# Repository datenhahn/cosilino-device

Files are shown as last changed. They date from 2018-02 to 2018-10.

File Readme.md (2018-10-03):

# Cosilino - Remote control Stiebel Eltron electronic heating applicances (ETS200-700) via MQTT



## Introduction

We live in an apartment fitted with these electronic heaters. They have two problems (besides
the generally bad efficency of electric heating):

1. They have one day of ineratia (they heat only at night and then keep the heat over a
   whole day). This means if the next day is unusually warm and you forget to switch them
   off the appartment is overheated the whole day. And in reverse, if you forget to switch
   them on, you have no way of "adhoc-heat".
2. The minimal setting is too hot for the transition seasons (autum, spring).

A colleague pointed me to the nice ESP8266 development board (thanks Ivan!) and with some
temperature sensors and a servo it is easy to turn this 15 year old heater into a fancy
IoT-device.

First I tried to use the DC control port which is powered by a DC current between
0.9 - 1.4 Volt , but then I ditched that idea because it would have required opening
the heater and fiddling with its internals which I didn't want to do (too risky).

The easy workaround was to just turn the max heat knob with a servo.

I 3D-printed the part to hold the servo with a cheap 40€ 3D print
pen which uses the normal 1,75mm PLA filament. It doesn't look nice
but it does the job. It is connected to the heating with magnets
(which I stole from my son's toy box).

The device's casing is way too big. This is the first prototype, so
I wanted to have some space to play around. Also I used an additional
NodeMCU breakout-board which makes using normal bread-board-connectors
 more convenient.

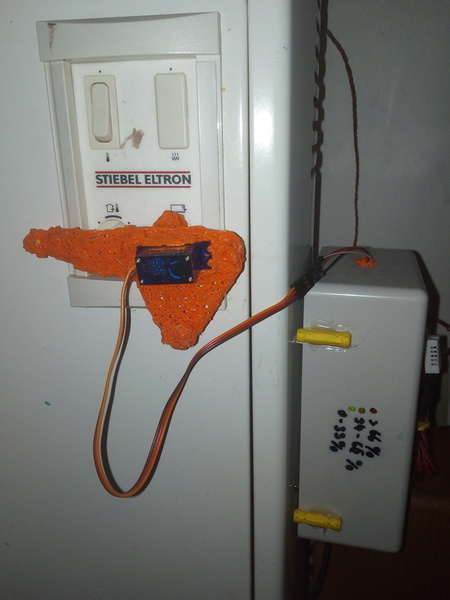
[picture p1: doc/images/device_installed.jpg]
Device installed


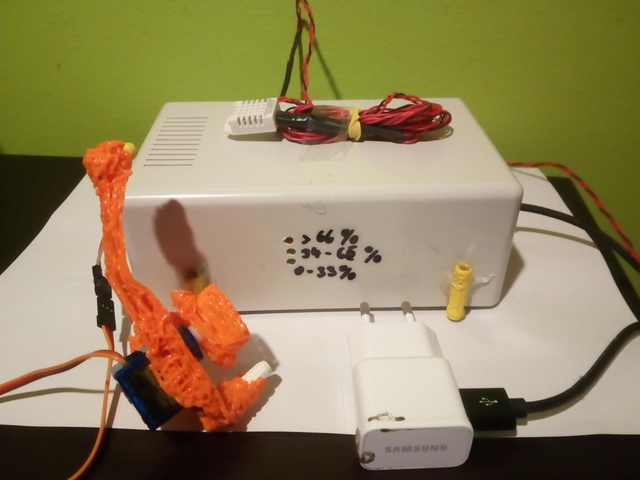
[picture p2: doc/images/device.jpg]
Device installed


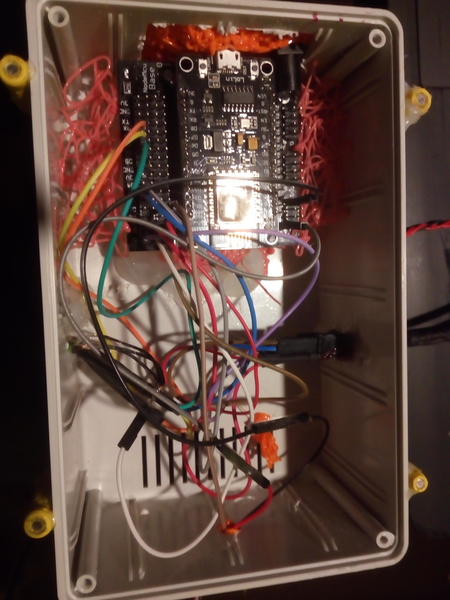
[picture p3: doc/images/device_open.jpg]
Device installed


### Watch in action

cosilino-video (https://www.youtube.com/watch?v=otGSGF0wK6k)

## cosilino-device

I built and flashed the firmware with the Arduino IDE. This folder contains the Arduino IDE ino-file for the device.

The device uses the WifiManager arduino lib (https://github.com/tzapu/WiFiManager).
If it cannot connect to a Wifi all LEDs will be on. You then can
connect to the devices accesspoint ( look for "cosilino-...) (... == deviceid).

You might have to adjust the mqtt server to your hostname/ip before
flashing.

    #define MQTT_SERVER "cosilino-gateway"

example for different ip:

    #define MQTT_SERVER "192.168.123.33"

### Anroid IDE plugins

I screenshotted all plugins I installed (see doc/arduino_ide_plugins).

### Material List

* ESP8266 (NodeMCU 1.0)
* Tower SG90 Micro Servo
* DHT-22 Temperature and Humidity-Sensor
* DS18S20 Temperature Sensor
* 1x red, 1x yellow, 1x green LEDs
* 3x 220Ohm resistor (for LEDs)
* 1x 1k Ohm resistor (pullup DHT-22)
* 1x 4,7k Ohm resistor (pullup DS18S20)
* RaspberryPi or any other permanently running pc (for MQTT broker + mongodb)

### Schematics

You find the fritzing file, schematics and plan in doc/fritzing.

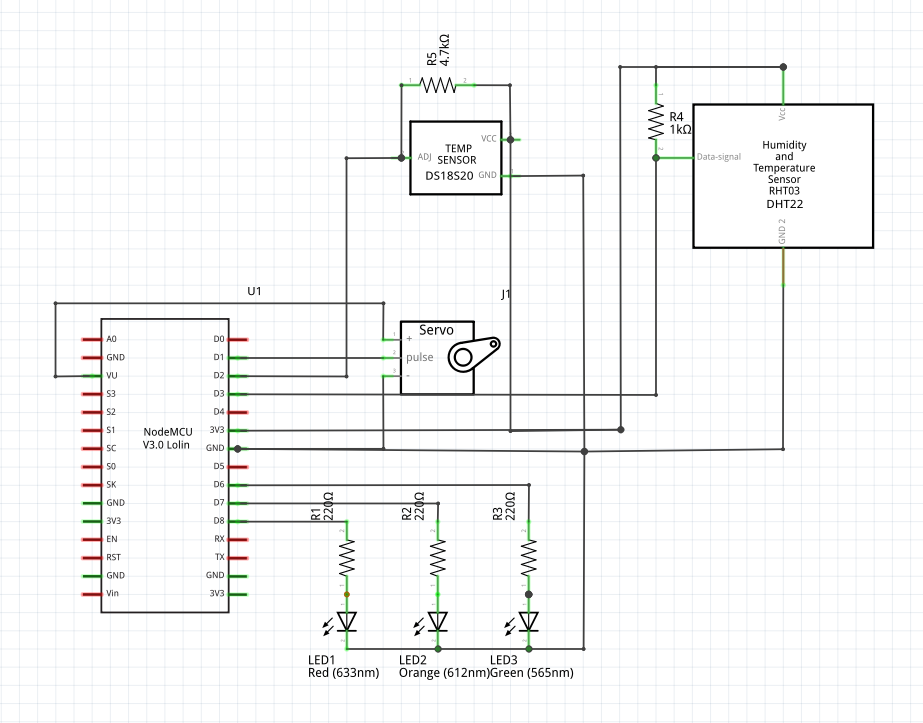
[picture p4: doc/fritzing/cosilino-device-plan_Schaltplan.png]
schematics


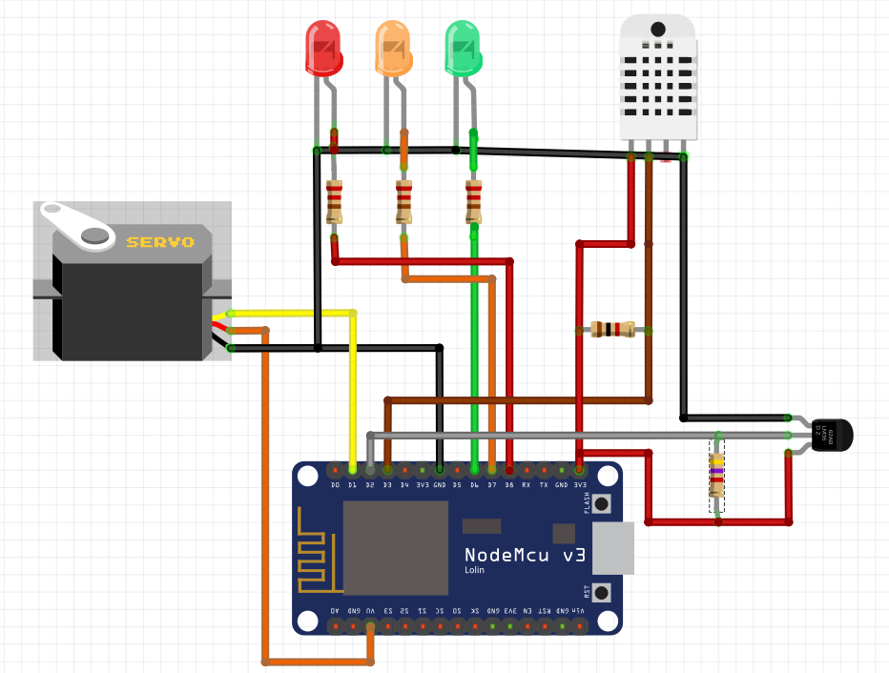
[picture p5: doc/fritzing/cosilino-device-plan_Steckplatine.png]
plan


## cosilino-backend

I used a raspberrypi with mosquitto and mongodb as backend.

```
apt-get install mosquitto mongodb-server
```

You might want to enable mongodb to your internal network by
commenting out

/etc/mongodb.conf

    #bind_ip = 127.0.0.1

Then restart mongodb (`/etc/init.d/mongodb restart`)

### Get and set heat

You can connect to all topics on the broker for debugging purposes.
`-v` also prints the topic names.

#### Read status messages

    $> mosquitto_sub -v -t "#"
    cosilino/171d45/status {"deviceId":"171d45","roomHum":51.80,"roomTemp":22.30,"heaterTemp":-127.00,"heaterPower":0}

#### Set heating level

For now I didn't implement any awesome logic. I just set up a cronjob
to switch the heater on for 1-2 hours at night. In winter it is on
all the time anyway and in summer off all the time. Of course a nice
automatic adjustment using a weather forecast would be nice (see todo).

Actually the percentage values aren't to helpful. In the end I controled
the heat by how long I set the heater to 100% (which is actually 66% as
the servo doesn't turn 270° but only 180°).

For me 1-2 hours per night was enough during autum/spring.

    $> mosquitto_pub -t "cosilino/171d45/heaterpower" -m 0
    $> mosquitto_pub -t "cosilino/171d45/heaterpower" -m 100

Example cronjobs

```
$> crontab -l
# For more information see the manual pages of crontab(5) and cron(8)
#
# m h  dom mon dow   command

#0 21 * * * mosquitto_pub -h cosilino-gateway -t cosilino/171d45/heaterpower -m 100
#45 21 * * * mosquitto_pub -h cosilino-gateway -t cosilino/171d45/heaterpower -m 0
#10 1  * * * mosquitto_pub -h cosilino-gateway -t cosilino/171d45/heaterpower -m 100
#30 1  * * * mosquitto_pub -h cosilino-gateway -t cosilino/171d45/heaterpower -m 0
#40 4 * * * mosquitto_pub -h cosilino-gateway -t cosilino/171d45/heaterpower -m 100
#0 5 * * * mosquitto_pub -h cosilino-gateway -t cosilino/171d45/heaterpower -m 0
```

### Pumping data into mongodb

I just run the backend in screen.

    apt-get install screen
    screen
    ./cosilino-backend.py

You might have to install an **older version of pymongo** as the mongodb version
which comes with raspbian is quite old (2.4..) .

## cosilino-mathplot

The plans to build a shiny webui were there, but for now I just built a
minimal gtk interface with mathplot lib.

You might have to install an **older version of pymongo** as the mongodb version
which comes with raspbian is quite old (2.4..) .

    ./cosilino-draw.py

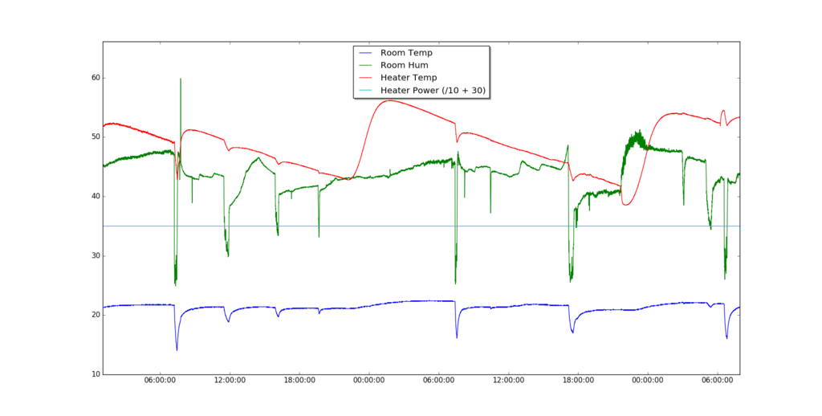
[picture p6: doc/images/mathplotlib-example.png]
stats example


## Todo

The real plan was to dynamically set the heat level depending on the
next days weather and condition (sun/clouds).

And of course it should be possible to access and control the devices
from the phone. So a nice webui should follow.

* add auto tune by getting weather forecast: https://openweathermap.org/
* add mobile-friendly webui

## Other resources

If you are interested in learning more about the heaters specs, have a look at the manual.

https://www.stiebel-eltron.com/content/dam/ste/cdbassets/current/bedienungs-_u_installationsanleitungen/ETS_200-700__89e3d3f0-fcf7-11e6-a5ac-005056a95add.pdf

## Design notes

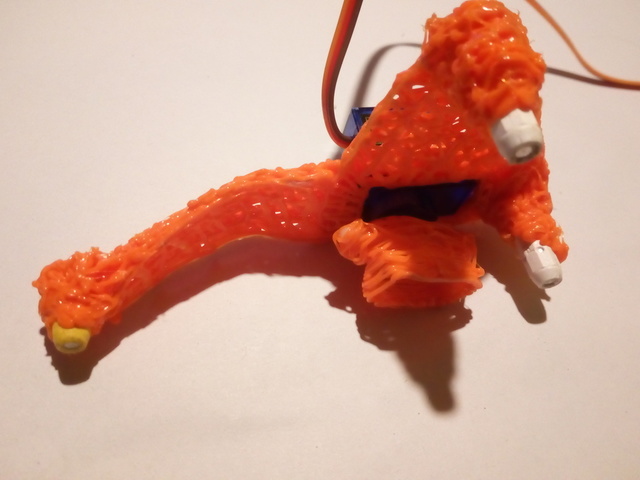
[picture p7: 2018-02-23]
doc/images/servo_2.jpg

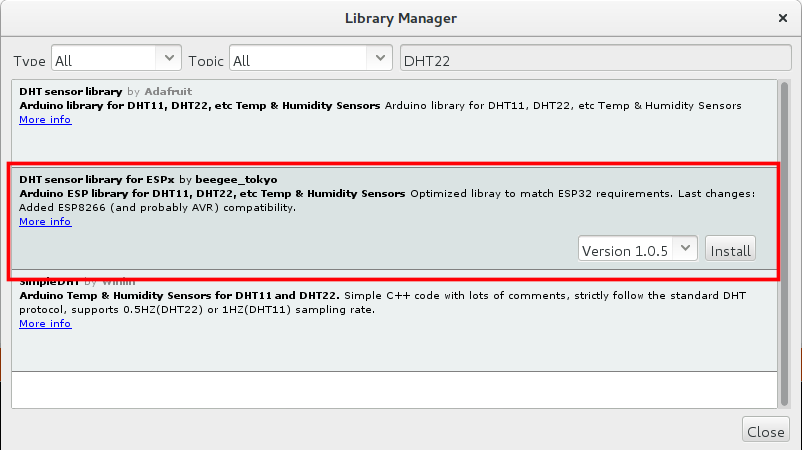
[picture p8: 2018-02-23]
doc/arduino_ide_plugins/Selection_298.png

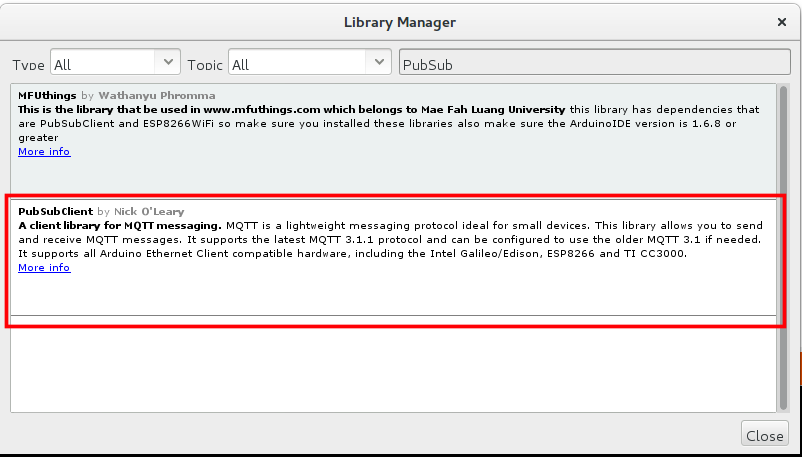
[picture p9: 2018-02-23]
doc/arduino_ide_plugins/Selection_299.png

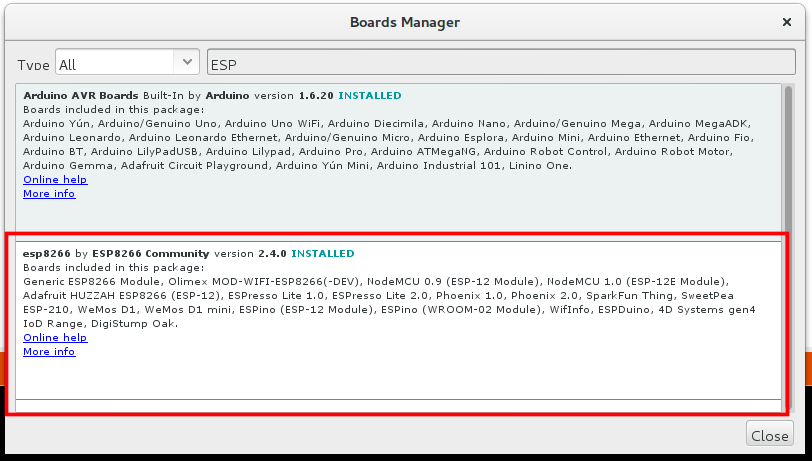
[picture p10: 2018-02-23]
doc/arduino_ide_plugins/Selection_295.png

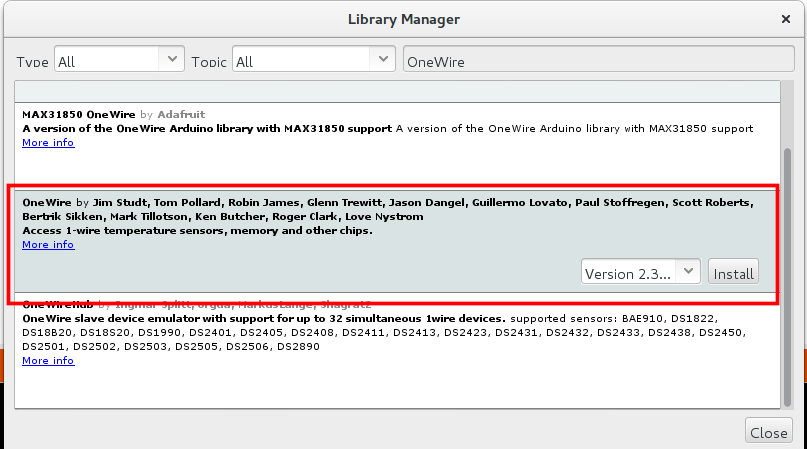
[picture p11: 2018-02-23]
doc/arduino_ide_plugins/Selection_296.png

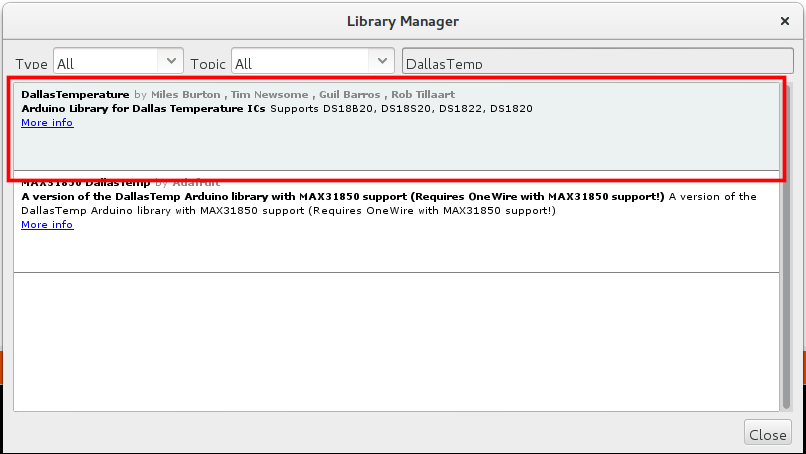
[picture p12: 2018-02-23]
doc/arduino_ide_plugins/Selection_297.png

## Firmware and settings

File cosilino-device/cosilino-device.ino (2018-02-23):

/*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
 * You should have received a copy of the GNU General Public License
 * along with this program.  If not, see <http://www.gnu.org/licenses/>.
 */

/*
 * cosilino (device software)
 *
 * This program for the ESP8266 reads temperatures from a DS18B20 temperature
 * sensor and a DHT-22 temperature and humidity sensor and allows to set
 * a servo turn degree from 0-180 in percent. (180° == 100).
 *
 * A status is published every 10 seconds on a mqtt topic and the servo commands
 * are read from a different topic.
 *
 * Author: Jonas Hahn <jonas.hahn@datenhahn.de>
 * */

#include <Servo.h>
#include <OneWire.h>
#include <DallasTemperature.h>
#include "DHTesp.h"
#include <ESP8266WiFi.h>
#include <PubSubClient.h>
#include <WiFiManager.h>

/* define ESP8266 pin usage*/
#define SERVO_PIN D1
#define PWM_PIN D4
#define RED_LED D8
#define YELLOW_LED D7
#define GREEN_LED D6
#define ONE_WIRE_BUS D2  // DS18B20 pin
#define DHTPIN D3
#define DHTTYPE DHT22 //DHT11, DHT21, DHT22

/* general constants */
#define MAX_SERVO_DEGREE 180
#define TOPIC_PREFIX "cosilino"
#define OUT_SUFFIX "status"
#define IN_SUFFIX "heaterpower"
#define MQTT_SERVER "cosilino-gateway"
#define DEFAULT_AP_PW "warmandcosy"
#define PUBLISH_INTERVAL_MS 10000

Servo servo;
WiFiManager wifiManager;
WiFiClient espClient;
PubSubClient client(espClient);
OneWire oneWire(ONE_WIRE_BUS);
DallasTemperature DS18B20(&oneWire);
DHTesp dht;

int globalHeatRatio = 0;
long lastMsg = 0;

void setup() {

    setupLedPins();
    Serial.begin(115200);

    flashLed(GREEN_LED, 5);

    Serial.println("Trying to reconnect wifi ...");

    wifiManager.setAPCallback(configModeCallback);
    String apName = "cosilino-" + getDeviceId();
    wifiManager.autoConnect(apName.c_str(), DEFAULT_AP_PW);

    onlyGreenLed();
    delay(500);

    dht.setup(DHTPIN);
    client.setServer(MQTT_SERVER, 1883);
    client.setCallback(callback);
    setHeatRatio(0);
}


void loop() {

    if (!client.connected()) {
        reconnect();
    }
    client.loop();

    long now = millis();
    if (now - lastMsg > PUBLISH_INTERVAL_MS) {
        lastMsg = now;
        publishMessage();
    }

}


/**
 * Called by WifiManager when it enters config mode.
 * Sets all LEDs to on.
 */
void configModeCallback(WiFiManager *myWiFiManager) {
    Serial.println("Entered config mode");
    Serial.println(WiFi.softAPIP());
    Serial.println(myWiFiManager->getConfigPortalSSID());
    allLedsOn();
}

void publishMessage() {
    float roomHumidity = dht.getHumidity();
    float roomTemperature = dht.getTemperature();

    DS18B20.requestTemperatures();
    float heaterTemperature = DS18B20.getTempCByIndex(0);

    String mqttMessage = "{\"deviceId\":\"" + getDeviceId() + "\",";
    mqttMessage += "\"roomHum\":" + String(roomHumidity) + ",";
    mqttMessage += "\"roomTemp\":" + String(roomTemperature) + ",";
    mqttMessage += "\"heaterTemp\":" + String(heaterTemperature) + ",";
    mqttMessage += "\"heaterPower\":" + String(globalHeatRatio) + "}";

    Serial.print("Publish message: ");
    Serial.println(mqttMessage.c_str());

    String outTopic = String(TOPIC_PREFIX) + "/" + getDeviceId() + "/" + OUT_SUFFIX;
    client.publish(outTopic.c_str(), mqttMessage.c_str());
}

void setHeatRatio(int heatRatio) {

    if (heatRatio < 0) {
        heatRatio = 0;
    }

    if (heatRatio > 100) {
        heatRatio = 100;
    }

    globalHeatRatio = heatRatio;

    if (heatRatio > 66) {
        onlyRedLed();
    } else if (heatRatio > 33) {
        onlyYellowLed();
    } else {
        onlyGreenLed();
    }

    int servoDegree = heatRatioToDegree(heatRatio);

    String output =
            "Setting: ratio=" + String(heatRatio) + " degree=" + String(servoDegree) + "\n";

    Serial.write(output.c_str());

    /* It is important here to attach and detach the servo. Otherwise it would constantly try to adjust its position,
     * which results in a constant buzzing noise if it is not able to move fully to the desired position.
     */
    servo.attach(SERVO_PIN);
    delay(100);
    servo.write(servoDegree);
    delay(2000);
    servo.detach();
}

int heatRatioToDegree(int heatRatio) {
    return MAX_SERVO_DEGREE * heatRatio / 100;
}

void callback(char *topic, byte *payload, unsigned int length) {
    Serial.print("Message arrived [");
    Serial.print(topic);
    Serial.print("] ");

    String input = String((char *) payload);
    int heatRatio = input.toInt();
    setHeatRatio(heatRatio);
}

String getDeviceId() {
    return String(ESP.getChipId(), HEX);
}

void reconnect() {
    // Loop until we're reconnected
    while (!client.connected()) {
        Serial.print("Attempting MQTT connection...");
        // Attempt to connect
        if (client.connect("ESP8266Client")) {
            Serial.println("connected");
                       
            String inTopic = String(TOPIC_PREFIX) + "/" + getDeviceId() + "/" + IN_SUFFIX;
            client.subscribe(inTopic.c_str());
        } else {
            Serial.print("failed, rc=");
            Serial.print(client.state());
            Serial.println(" try again in 5 seconds");
            // Wait 5 seconds before retrying
            delay(5000);
        }
    }
}

/**
 * LED control
 */

void flashLed(int led, int times) {
    digitalWrite(led, HIGH);

    for (int i = 0; i < times; i++) {
        delay(500);
        digitalWrite(led, LOW);
    }
}

void setupLedPins() {
    pinMode(PWM_PIN, OUTPUT);
    pinMode(RED_LED, OUTPUT);
    pinMode(YELLOW_LED, OUTPUT);
    pinMode(GREEN_LED, OUTPUT);
    allLedsOff();
}

void allLedsOff() {
    digitalWrite(RED_LED, LOW);
    digitalWrite(YELLOW_LED, LOW);
    digitalWrite(GREEN_LED, LOW);
}

void allLedsOn() {
    digitalWrite(RED_LED, HIGH);
    digitalWrite(YELLOW_LED, HIGH);
    digitalWrite(GREEN_LED, HIGH);
}

void onlyRedLed() {
    allLedsOff();
    digitalWrite(RED_LED, HIGH);
}

void onlyYellowLed() {
    allLedsOff();
    digitalWrite(YELLOW_LED, HIGH);
}

void onlyGreenLed() {
    allLedsOff();
    digitalWrite(GREEN_LED, HIGH);
}

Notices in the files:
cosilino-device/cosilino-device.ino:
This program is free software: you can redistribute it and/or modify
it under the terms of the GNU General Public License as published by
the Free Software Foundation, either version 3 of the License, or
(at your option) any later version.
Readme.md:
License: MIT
